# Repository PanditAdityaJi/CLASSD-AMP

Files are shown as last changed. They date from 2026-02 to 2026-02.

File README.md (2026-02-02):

# Class-D Audio Amplifier — NE555 PWM

A low-power Class-D audio amplifier built around the NE555 timer as a PWM generator. The design covers the full signal path from microphone/line input to an 8 Ω speaker, with LTspice simulation and a KiCad PCB layout included.

---

## How It Works

```
Audio In ──► opamp ──► NE555 ──► BJT Driver ──► PMOS/NMOS ──► LC Filter ──► Speaker
            Comparator   PWM      (Q1/Q2)        Half-Bridge    33µH/470nF
```

The audio signal and a triangle carrier are compared by an op-amp running open-loop. The comparator output triggers the NE555, which produces a PWM waveform whose duty cycle tracks the audio amplitude. A complementary BJT pair buffers the PWM to fast-charge the MOSFET gates of an (PMOS) /  (NMOS) half-bridge. An LC low-pass filter strips the switching harmonics, leaving a clean audio signal for the speaker.

## NE555 Pin Connections

| Pin | Name | Connection |
|-----|---|---|
| 1 | GND  | Ground plane |
| 2 | TRIG | Triangle carrier via 1 nF AC-coupling cap (C2) |
| 3 | OUT  | PWM → gate driver through 100 Ω series resistor (R6) |
| 4 | RST  | Tied directly to VCC — **never** to OUT |
| 5 | CV | 10 nF cap (C3) to GND — decouples internal divider |
| 6 | THRS | Timing capacitor + R3/R4 network |
| 7 | DIS  | Between R3 (1 kΩ) and R4 (3.3 kΩ) |
| 8 | VCC  | 12 V supply |

---

## Key Design Decisions

**Why NE555 instead of a microcontroller?** Frequency is set entirely by passive components — no firmware, no clock dependency.

**Why a BJT driver stage?** Power MOSFETs have several nF of gate capacitance. Driving them straight from the 555 output produces slow edges and shoot-through overlap. The emitter follower charges and discharges the gates in tens of nanoseconds.

**Why PMOS + NMOS instead of dual N-channel with a bootstrap?** Simpler gate drive — no floating supply needed for the high side. The pair has low enough R_DS(on) (0.5–1.5 Ω) that conduction loss is small against the 8 Ω load.

**Why 100 Ω on the gate (R6)?** Without it the gate trace resonates with the MOSFET input capacitance at hundreds of MHz. 100 Ω damps the ring without slowing the edge enough to increase switching loss.

**Why 33 µH / 0.47 µF for the LC filter?** The cut-off lands at roughly 300 kHz, giving >40 dB/decade roll-off. Film caps were specified over ceramics because ceramics of this value suffer severe DC-bias derating that would shift the pole under signal swing.

**Why matched R5 = R8 = 1 kΩ in the triangle generator?** Equal resistors make the rising and falling slopes identical, producing a symmetric carrier. An asymmetric carrier introduces even-order harmonics and a DC offset at the speaker.

---

## Bill of Materials

| Ref | Part | Value | Notes |
|-----|---|---|---|
| U1 | NE555D | — | SOIC-8 |
| U2 | LMV321 | — | SOT-23-5, open-loop comparator |
| Q1 | 2N3904 | — | NPN gate driver |
| Q2 | 2N3906 | — | PNP gate driver |
| Q3 | IRF9540 | — | PMOS high-side switch |
| Q4 | IRF540  | — | NMOS low-side switch |
| L1 | Inductor | 33 µH | Ferrite core, ≥ 3 A rated |
| R1 | Resistor | 100 kΩ | Input bias divider |
| R2 | Resistor | 100 kΩ | Input bias divider |
| R3 | Resistor | 1 kΩ | 555 timing (charge) |
| R4 | Resistor | 3.3 kΩ | 555 timing (discharge) |
| R5 | Resistor | 1 kΩ | Triangle generator |
| R6 | Resistor | 100 Ω  | Gate series damping |
| R7 | Resistor | 8 Ω | Speaker load |
| R8 | Resistor | 1 kΩ | Triangle generator |
| C1 | Capacitor | 10 nF  | Audio input AC-coupling |
| C2 | Capacitor | 1 nF | TRIG AC-coupling |
| C3 | Capacitor | 10 nF  | CV pin bypass |
| C4 | Capacitor | 10 nF  | Triangle timing |
| C5 | Capacitor | 0.47 µF | LC filter (film) |
| C6 | Capacitor | 0.47 µF | Output filter / DC-block (film) |
| J2 | Connector | 2-pin | Power input (24 V) |
| J3 | Connector | 2-pin | Audio input |
| J4 | Connector | 2-pin | Speaker output |
| LS1 | Speaker | 8 Ω | — |

---

## Simulation

Simulated end-to-end in LTspice with a 1 kHz / 0.5 V sine test tone.

**Verified nodes:**

- **V(triangle)** — symmetric carrier, 3.4–3.6 V swing at the carrier frequency.
- **V(gate)** — clean PWM from the 555 output stage.
- **V(switching)** — half-bridge output, full rail-to-rail (0 V ↔ 24 V).
- **V(audio_out)** — filtered output; residual ripple is only a few millivolts.

**FFT results:**

- Audio_out shows the 1 kHz tone near −55 dB with harmonics below −140 dB across the audio band.
- Switching node shows the expected carrier and odd harmonics near 100 kHz.

---

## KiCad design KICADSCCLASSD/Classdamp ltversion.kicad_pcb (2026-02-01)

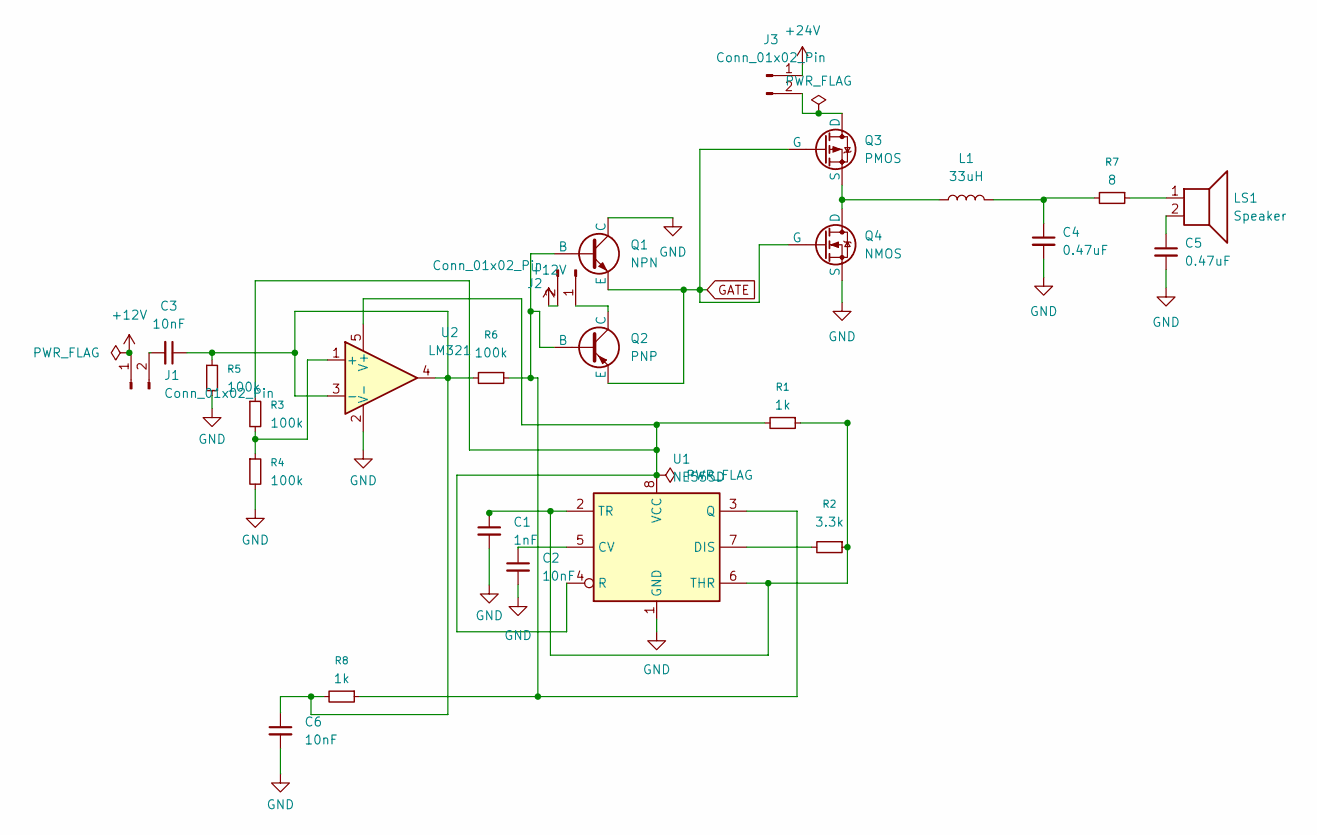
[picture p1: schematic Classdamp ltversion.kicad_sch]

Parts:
C1: 1nF; C_0201_0603Metric_Pad0.64x0.40mm_HandSolder
C2, C3, C6: 10nF; C_0402_1005Metric_Pad0.74x0.62mm_HandSolder
C4, C5: 0.47uF; C_0402_1005Metric_Pad0.74x0.62mm_HandSolder
J1, J2, J3: Conn_01x02_Pin; PhoenixContact_MCV_1,5_2-GF-5.08_1x02_P5.08mm_Vertical_Thre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
L1: 33uH; L_1206_3216Metric_Pad1.22x1.90mm_HandSolder
LS1: Speaker; MagneticBuzzer_ProSignal_ABT-410-RC
Q1: NPN; SOT-23
Q2: PNP; SOT-23
Q3: PMOS; TO-92
Q4: NMOS; TO-92
R1, R8: 1k; R_0201_0603Metric_Pad0.64x0.40mm_HandSolder
R2: 3.3k; R_0201_0603Metric_Pad0.64x0.40mm_HandSolder
R3, R4, R5, R6: 100k; R_0508_1220Metric_Pad1.12x2.15mm_HandSolder
R7: 8; R_0612_1632Metric_Pad1.18x3.40mm_HandSolder
U1: NE555D; SOIC-8_3.9x4.9mm_P1.27mm
U2: LM321; SOT-23-5

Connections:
+12V: J1.1, J2.2
+24V: J3.1
GATE: Q1.3 (E), Q2.3 (E), Q3.2 (G), Q4.2 (G)
GND: C1.2, C2.2, C4.2, C5.2, C6.2, Q1.1 (C), Q4.3 (S), R4.2, R5.2, U1.1 (GND), U2.2 (V-)
unnamed: C4.1, L1.2, R7.2
unnamed: C5.1, LS1.2
unnamed: C3.2, J1.2
unnamed: J2.1, Q2.1 (C)
unnamed: J3.2, Q3.1 (D)
unnamed: LS1.1, R7.1
unnamed: Q1.2 (B), Q2.2 (B), R6.1, R8.1, U1.3 (Q)
unnamed: L1.1, Q3.3 (S), Q4.1 (D)
unnamed: C2.1, U1.5 (CV)
unnamed: R2.2, U1.7 (DIS)
unnamed: R1.2, R3.1, U1.4 (R), U1.8 (VCC), U2.5 (V+)
unnamed: C1.1, R1.1, R2.1, U1.2 (TR), U1.6 (THR)
unnamed: R3.2, R4.1, U2.1 (+)
unnamed: C3.1, C6.1, R5.1, R6.2, R8.2, U2.3 (-), U2.4

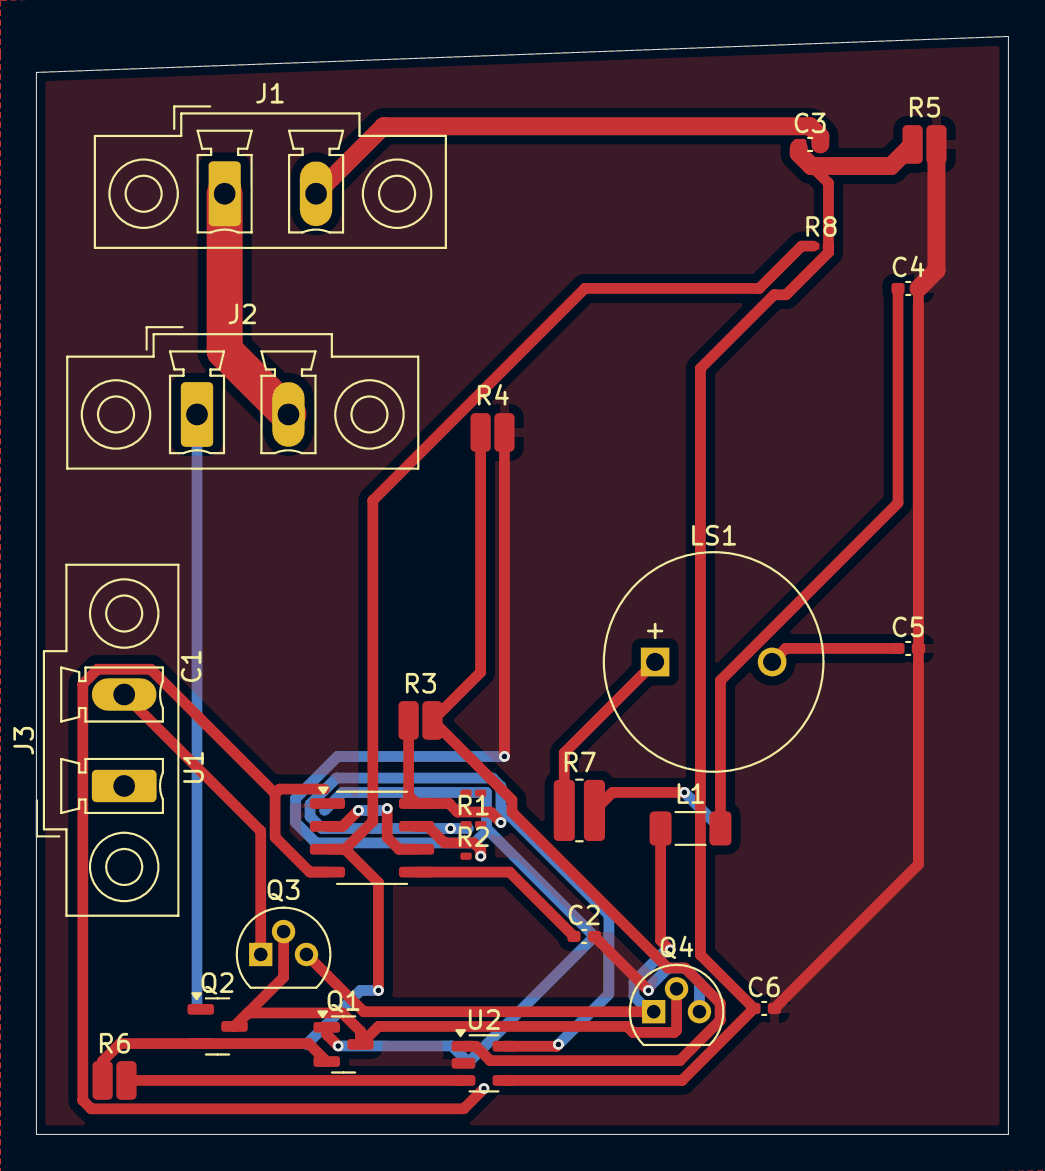
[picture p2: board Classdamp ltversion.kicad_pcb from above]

Board: 2 copper layers, 54.0 x 61.0 mm, 25 parts (0 on the bottom side), 17 nets.
